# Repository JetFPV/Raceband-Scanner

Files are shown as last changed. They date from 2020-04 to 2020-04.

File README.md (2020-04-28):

# Raceband Scanner

**This device is a  scanner for the RaceBand 5.8G to check available channels for FPV Pilots.  
The result is shown on the device using LEDs and a screen can be added to view the scanning graph or display the video feed from the selected channel. The device can be used on the field using a lipo battery (3 to 6S) or at home with micro usb.**  

<p align="left">
  
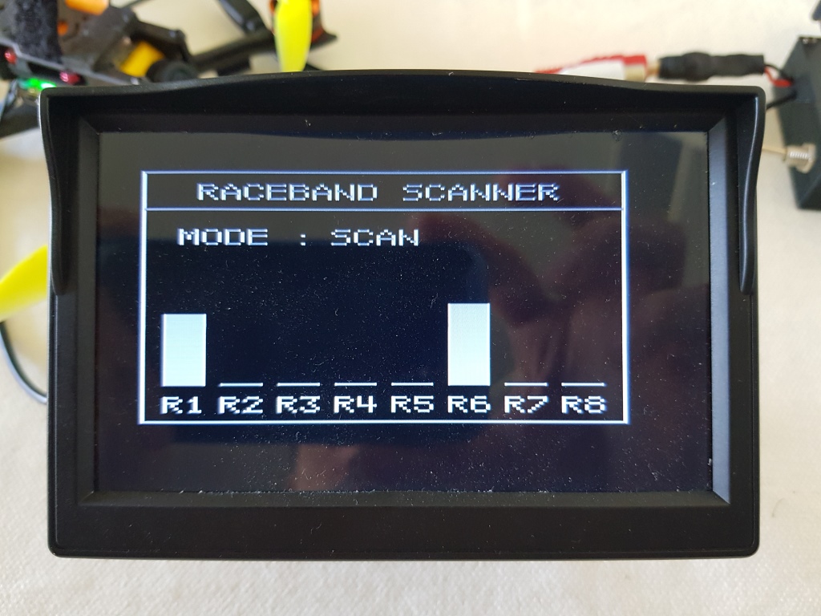
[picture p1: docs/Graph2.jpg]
  
  
</p>

## NEWS FEED
------------------------------------------------
- 2020-04: First version of the project released 
------------------------------------------------

## Contents

<!-- MarkdownTOC depth=0 bracket="round" autolink="true" autoanchor="true" -->

- [Features](#features)
- [Used parts](#used-parts)
- [Wiring](#wiring)
- [3D Case](#3d-case)
- [Arduino Code](#arduino-code)
- [User Guide](#user-guide)
- [Recognition](#recognition)
- [Contributors](#contributors)

<!-- /MarkdownTOC -->

## Features
- Can display video from the drone on the 5,8Ghz Raceband
- Can scan the 8 channels to check if there is a signal and display result on Led and screen if available
- 3 modes included : Manual / Automatic / Scanner    
	=> Manual : Change manually channel from R1 to R8    
	=> Automatic : Switch to channel whith highest signal on   
	=> Scanner : Display available channels on the LEDs and show graph on the screen    
- Power supply by Lipo battery (3 to 6S) or Micro USB Port (for the device only, use external power for the screen in that case)
- Lipo voltage monitoring : Display level of batery when plugging the battery and check if low during usage (turn red + beep)
- Mario Bross sounds ;-)

## Used parts

- 1x PCB Prototype board 50x70mm => https://banggood.app.link/N559qmOQJ5
- 1x RX5808 Module 5.8G Receiver module => https://banggood.app.link/6v3u5r1tJ5
- 1x Passive Buzzer 12mm (Optional) => https://banggood.app.link/EE6gt1oLJ5
- 2x Push Buttons Switch Momentary => https://banggood.app.link/4OSGzJBLJ5 or from kit https://banggood.app.link/t9bOLoGLJ5
- 1x DC-DC Step down converter (set to 9V) => https://banggood.app.link/IfqrpMOLJ5
- 1x 8 LEDS WS2812 5050 RGB => https://banggood.app.link/PKKfUEVLJ5
- 1x Arduino nano V3 : https://banggood.app.link/OwPY6x5LJ5
- 5x Resistors => (2x 220 / 2x 1k / 1x 470)
- 1x XT60 => https://banggood.app.link/CkOhsbz5N5
- 8x M2 Screws 4mm
*** Optional screen but nice to have :) ***
- 1x TFT LCD FPV Mini Monitor Screen Displayer (Optional) => https://banggood.app.link/BduELWmQJ5
- 1x RCA Female => https://banggood.app.link/1RLBWa3KJ5
- 1x DC Male => https://banggood.app.link/rKf3vaM5N5
- 1x 2 positions ON/ON switch : https://banggood.app.link/S85dgTBMJ5

## Wiring

I used the PCB Prototype 50x70 board for wiring.<br>
Use the schematic and pictures bellow to locate the component exactly the same if you intend to use the 3D Printed case, especially XT60, the 2 buttons and the arduino nano

Don't forget to set DC-DC Stepdown cenverter to 9V-10V using a small screwdriver and a multimeter.<br>
I noticed 12V is too much for the arduino (at least for a clone...).

<p align="left">
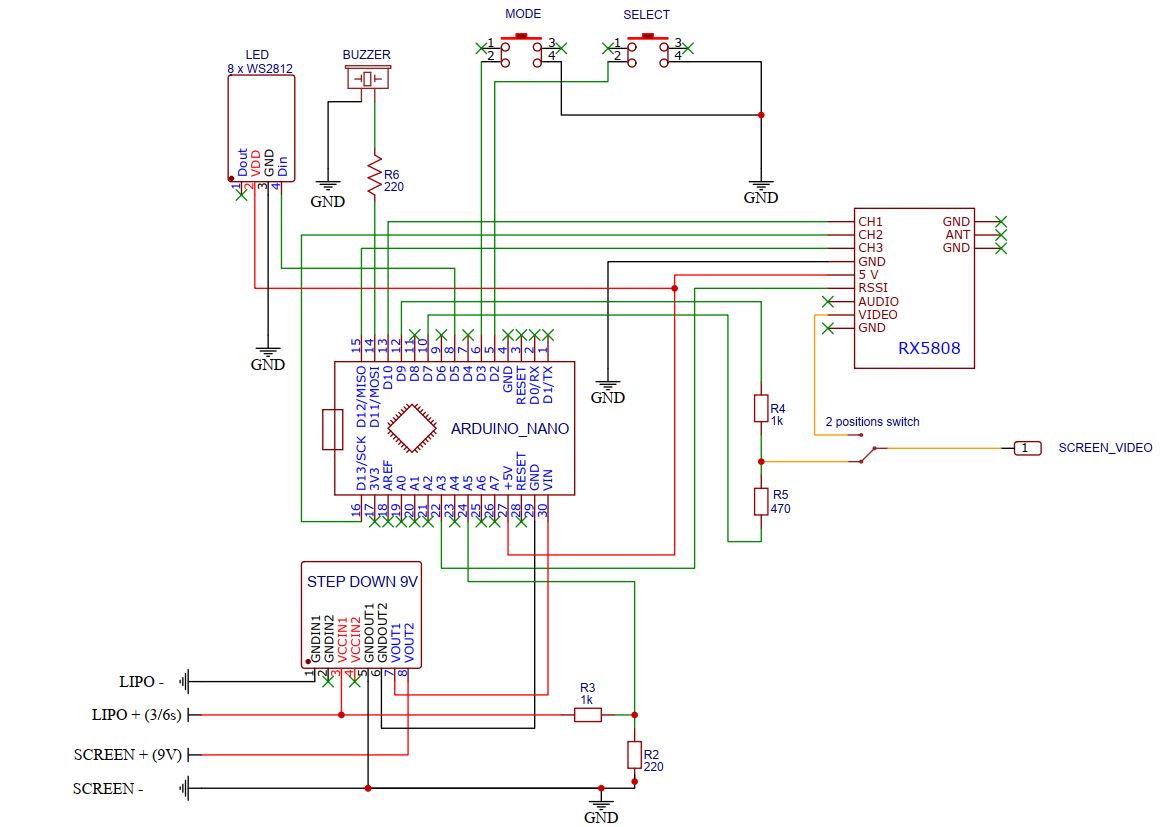
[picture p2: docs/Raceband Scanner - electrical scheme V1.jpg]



</p>

## 3D Printed Case

STL file is available in 3D case folder.   
Print in PLA with 100% infill.   
You will need 8 small M2 screws (3 / 4mm) to assemble PCB into the case and close the lid.    

<p align="left">
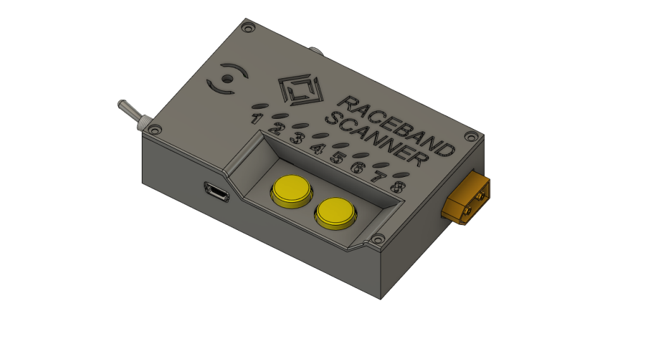
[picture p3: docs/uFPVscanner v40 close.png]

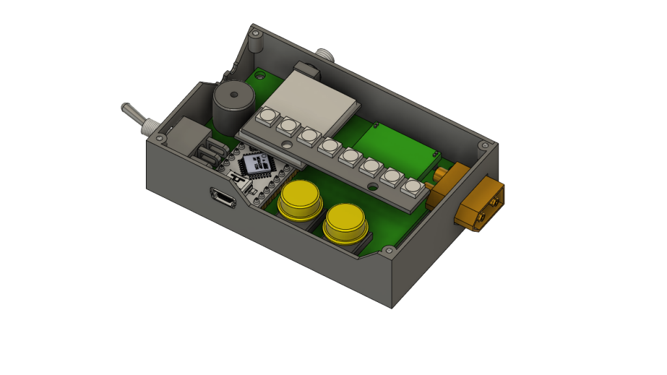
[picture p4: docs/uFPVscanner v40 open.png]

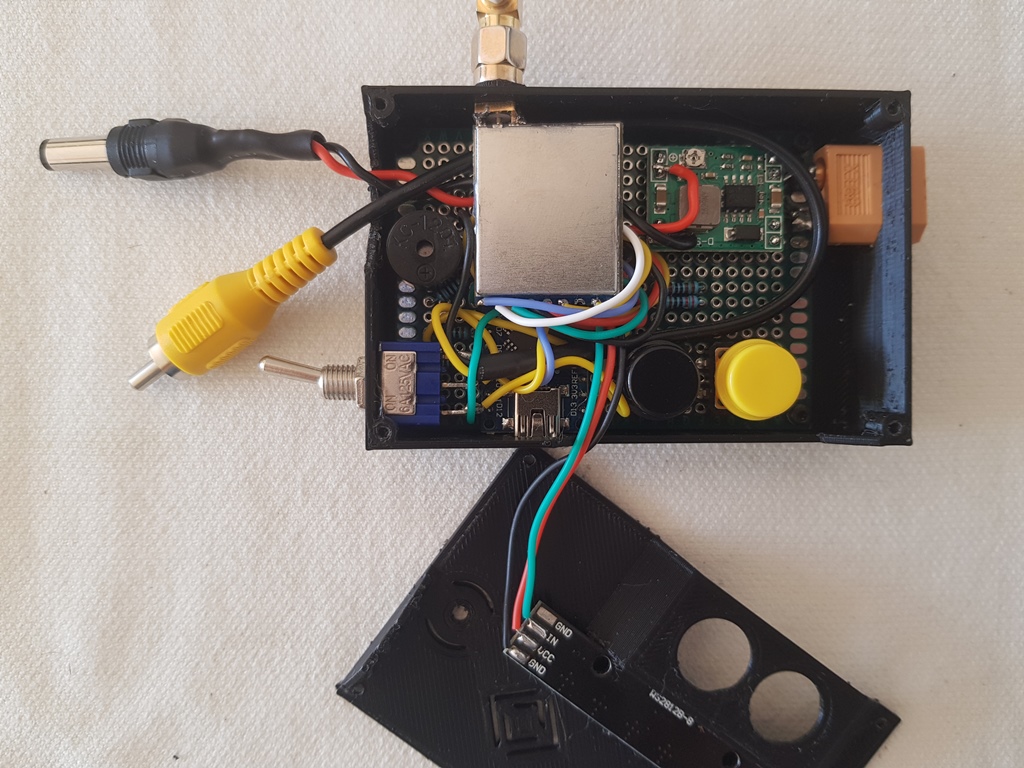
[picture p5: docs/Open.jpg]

</p>

## Arduino Code

Download the project from Arduino folder, open **Raceband_Scanner.ino** file with Arduino IDE (https://www.arduino.cc/en/main/software) and upload to the arduino nano.
In Arduino IDE -> Sketch -> Include Library -> Manage Libraries, search and install for **"FastLED"** and **"TVout"**

Note : FastLED might give you a warning message about version compatibility during upload which is OK.

The code is distrubuted under the MIT license.

## User Guide

When powered with LIPO, first bargraph show LIPO Status :
- 4 to 8 LEDs ON = Green => OK (about >3,8V / Cell)
- 2 to 3 LEDs ON = Orange => Storage (about 3,5 to 3,8V / Cell)
- 1 LED = Red => Low Battery (<3.5V / Cell)

Then Lipo show **Blue** Led showing selected channel.
   
**Buttons :**
- BLACK => Change Mode (Show the mode in **purple** LED)
- YELLOW => Select
    
**MODE button switch between modes :**
- Mode 1 (1 purple led) : Manual change of channel with Select button
- Mode 2 (2 purple leds) : Search for channel with highest signal when pressing select
- Mode 3 (3 purple leds) : Scanner mode, show green for available channels and red for busy channel
 
Raceband Scanner Video (https://youtu.be/IBXWHqRhws8)

## Recognition

- SPI driver based on fs_skyrf_58g-main.c by Simon Chambers
- TVOUT by Myles Metzel

## Contributors

Contributors are very welcome, I'm not either a professional developper nor a professional electronician.<br>
The code and schematic can probably be improved a lot.

For next versions, here is a list of possible improvement in my head :
- Custom PCB
- Use interuptions for better reaction of buttons
- Slide button with 6 poles instead of toggle switch to get input from the video switch and therefore be used as Mode button (Video <=> Scanner)
- Have only one button
- Make it smaller
- Integrate DC screen supply & video directly in the case

Feel free to ask questions, suggest improvements, report your usage results.

=> Happy flying ! <=

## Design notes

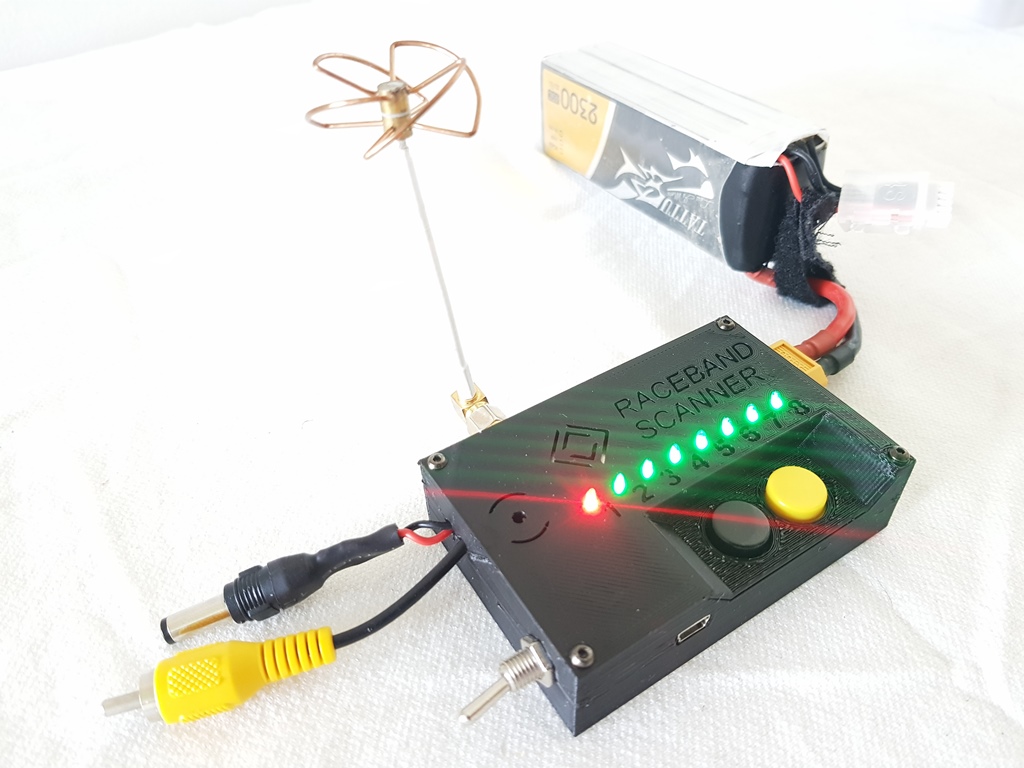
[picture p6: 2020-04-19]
docs/Raceband Scanner 1.jpg

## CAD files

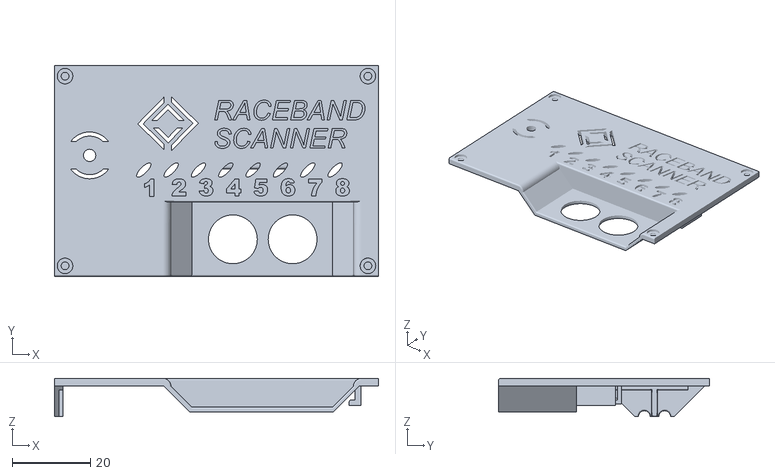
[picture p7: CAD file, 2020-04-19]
3D Case/RACEBAND SCANNER - Upper case V1_4.stl
83.0 x 54.0 x 9.77

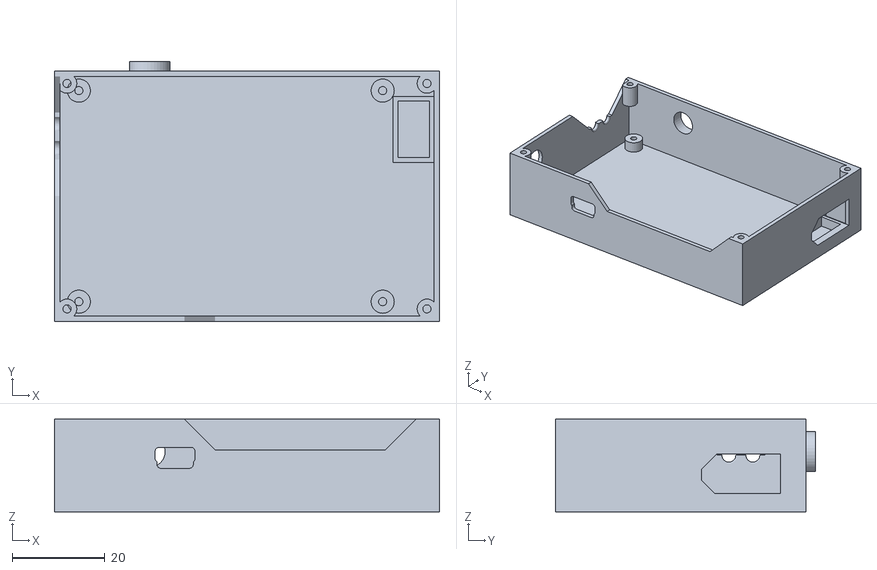
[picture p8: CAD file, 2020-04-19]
3D Case/RACEBAND SCANNER - Lower case V1_4.stl
83.0 x 56.0 x 20.0

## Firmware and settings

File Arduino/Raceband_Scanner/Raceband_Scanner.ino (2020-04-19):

/**
 * DIY RAceband Scanner by Jérémie Tondu (Jet FPV)
 * SPI driver based on fs_skyrf_58g-main.c by Simon Chambers
 * TVOUT by Myles Metzel

The MIT License (MIT)

Copyright (c) 2020 by Jérémie Tondu (Jet FPV)

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
THE SOFTWARE IS PROVIDED "AS IS", WITHOUT WARRANTY OF ANY KIND, EXPRESS OR
IMPLIED, INCLUDING BUT NOT LIMITED TO THE WARRANTIES OF MERCHANTABILITY,
FITNESS FOR A PARTICULAR PURPOSE AND NONINFRINGEMENT. IN NO EVENT SHALL THE
AUTHORS OR COPYRIGHT HOLDERS BE LIABLE FOR ANY CLAIM, DAMAGES OR OTHER
LIABILITY, WHETHER IN AN ACTION OF CONTRACT, TORT OR OTHERWISE, ARISING FROM,
OUT OF OR IN CONNECTION WITH THE SOFTWARE OR THE USE OR OTHER DEALINGS IN THE
SOFTWARE.
*/

// TVout setup
#include <avr/pgmspace.h>
#include <TVout.h>
#include <fontALL.h>

// Configuration of RX5808 VRX
#define RSSI_ADC A3 // RSSI pin on Arduino A3
#define SPI_DATA_PIN 10 // CH1 pin RX5808 => D10
#define SPI_SS_PIN 13 // CH2 pin RX5808 => D13
#define SPI_CLOCK_PIN 12 // CH3 pin RX5808 => D12
#define RSSI_AVERAGE_READS 5 // Number of ADC reads (averaged) per iteration
#define RSSI_THRESHOLD 200
#define MIN_RSSI 135 // Check RSSI when nothing is plugged
#define MAX_RSSI 270 // Check RSSI when drone is plugged next to RX5808
#define MIN_BAR_OFFSET 35
#define MAX_BAR_OFFSET 80

// Configuration of other pins
#define BUZZER_PIN 11 // Buzzer pin is defined by TVout on pin 11
#define BUTTON_M 3 // Button MODE on Pin 2
#define BUTTON_S 2 // Button SELECT on Pin 3

// Lipo monitor Input
#define LIPO_ADC A5 // Lipo voltage divider input on A5
#define LIPO_AVERAGE_READS 5 // Number of ADC reads (averaged) per iteration
#define VOLTAGE_CIRCUIT 5 // Voltage of input circuit for accurate reading of LIPO Voltage
#define LIPO_MIN_V 3.2 // Voltage minimum for each cell of lipo
#define LIPO_MAX_V 4.2 // Voltage maximum for each cell of lipo

// Global variable declaration and initialization
byte channelDetected = 1;
byte channelSelect = 1; // By default channel is 8 (only very first startup)
byte bandSelect = 0; // 0 is Raceband - Change for following : 1 Band A - 2 Band B - 3 Band E - 4 Band F - 5 Band D
uint16_t rssi = 0;
uint16_t rssiMax = 0;
uint16_t rssiScaled;
byte caddxPos = 0;
byte storedChannel;
byte channelTV;
bool lipoLow = false;
bool stateM;
bool stateO;
byte mode = 1; 
bool action = false;
bool out = false;
bool outM = false;
bool outO = false;

// LED Setup
#include "FastLED.h"
#include <avr/pgmspace.h>
#define DATA_PIN 5
#define NUM_LEDS 8
CRGB leds[NUM_LEDS];

// Include internal headers & other librairies
#include "rx5808spi.h"
#include "leds.h"
#include "lipo.h"
#include "pitches.h"
#include <EEPROM.h>

TVout TV;

//------ SETUP PART --------------------------------------------------------------------------------------

void setup() {
       
    // initialisation des pin
    pinMode(SPI_SS_PIN, OUTPUT);
    pinMode(SPI_DATA_PIN, OUTPUT);
    pinMode(SPI_CLOCK_PIN, OUTPUT);
    pinMode(BUTTON_M, INPUT_PULLUP);
    pinMode(BUTTON_S, INPUT_PULLUP);
    
    // LEDS setup
    FastLED.addLeds<NEOPIXEL, DATA_PIN>(leds, NUM_LEDS);
    Clearleds();
    FastLED.show();

    // Display lipo status on LED
    ShowlipoStatus(); 

    // Start on mode 1 (manual)
    mode = 1;
  
    // Channel select on RX5808 based on EEPROM if exist & set in RX5808
    storedChannel = EEPROM.read(0);
    if ( storedChannel <=8 ){
        channelSelect = storedChannel;
    }
    setChannelModule(channelSelect, bandSelect);
    SetLed(channelSelect);

    //Setup display. (PAL/NTSC, resolution width, resolution height)
    TV.begin(PAL,128,96);
    TV.select_font(font4x6);
    TV.clear_screen();
}

//************************************* MAIN PROGRAM **********************************************************

void loop() {
  
//------------------- GET BUTTON STATUS & MODE / ACTION CHANGE ----------------

    stateM = digitalRead(BUTTON_M);
    stateO = digitalRead(BUTTON_S);

    if ((stateM == LOW && stateO == HIGH) || outM == true) {
        delay(50);
        if (mode<3) { mode++;}
          else { mode = 1; }
        SetLedMode(mode);
        delay(800);
        Clearleds();
        if (mode == 1 || mode == 2) 
        {
          setChannelModule(channelSelect, bandSelect);
          SetLed(channelSelect);
        }
        TV.draw_rect(2, 20,123, 70, BLACK, BLACK);
        outO = false;
        outM = false;
        out = false;
        }    
    else if ((stateO == LOW && stateM == HIGH)  || outO == true) {
        delay(50);
        action = true;
        outO = false;
        outM = false;
        out = false;
        }
    else { 
          action = false; 
        }

//-------------------- TV SCREEN INIT -----------------------------------------
  
      // Display border, tiltle, channel and rssi on the screen
      TV.select_font(font6x8);
      TV.print(15, 5,"RACEBAND SCANNER");
      TV.draw_rect(0,0,127,94,WHITE);
      TV.draw_line(0,14,127,14,WHITE);

       channelTV = 48 + channelSelect;
       TV.print(10, 22, "MODE : ");
       TV.draw_rect(90,22,35,8,BLACK, BLACK);
       if (mode == 1) { TV.print(50, 22, "MANUAL"); } 
       if (mode == 2) { TV.print(50, 22, "AUTO"); }
       if (mode == 3) { TV.print(50, 22, "SCAN"); }

       if (mode == 1 || mode == 2)
       {
          rssi = GetRssi();
          TV.print(10, 32, "CHANNEL : R");
          TV.print(78, 32, channelTV);
          rssi = GetRssi();
          TV.print(10, 42, "RSSI : ");
          rssi = constrain(rssi, MIN_RSSI, MAX_RSSI);
          rssiScaled = map(rssi, MIN_RSSI, MAX_RSSI, 0, 100);
          TV.print(50, 42, rssi);// Display raw number 
          //TV.print(105, 42, "%"); // Display RSSI in %
       }
                
 //--------------- MODE 1 = MANUAL CHANGE OF RACEBAND CHANNEL -----------------  
      if (mode == 1)
      {
          if (action == true)
              {
              channelSelect++;
              if (channelSelect == 9) { channelSelect = 1; }
              setChannelModule(channelSelect, bandSelect);
              SetLed(channelSelect);
              TV.tone(NOTE_G4,35);
              delay(35);
              TV.tone(NOTE_G5,35);
              delay(35);
              TV.tone(NOTE_G6,35);
              delay(35);
              TV.noTone(); 
              }      
          }
 //--------------- MODE 2 = AUTOMATIC : AUTO LOCK ON MAX RSSI DETECTED ---------
  
      if (mode == 2 && action == true)
      {
        // Detect Raceband Channel with higher RSSI & Set RX5808 to this channel
        channelDetected = ChannelMaxRssi();
        if ( (channelDetected != channelSelect) && (channelDetected != 0) )
        {
            channelSelect = channelDetected;
            setChannelModule(channelSelect, bandSelect);
            SetLed(channelSelect);
            TV.tone(NOTE_E6,125);
            delay(130);
            TV.tone(NOTE_G6,125);
            delay(130);
            TV.tone(NOTE_E7,125);
            delay(130);
            TV.tone(NOTE_C7,125);
            delay(130);
            TV.tone(NOTE_D7,125);
            delay(130);
            TV.tone(NOTE_G7,125);
            delay(125);
            TV.noTone();
        }
        else {
            setChannelModule(channelSelect, bandSelect);
            SetLed(channelSelect);
        }
      }
 //--------------- MODE 3 = SCANNER MODE -------------------------------------
   
      if (mode == 3)
      {
              TV.draw_rect(2, 30,123, 60, BLACK, BLACK);          
              for (byte i = 1; i < 9; i++) 
                  {
                  channelTV = 48 + i;
                  TV.select_font(font6x8);  
                  TV.print((15*i)-9, 85, "R");
                  TV.print((15*i)-3, 85, channelTV);
                  rssi = RaceBandScan(i);
                  if (rssi < RSSI_THRESHOLD) { 
                        leds[i-1] = CRGB::Green; }
                  else {
                        leds[i-1] = CRGB::Red; }
                  }
              outM = false;
              outO = false;
              out = false;
              FastLED.show();
              do {
               for (byte i = 1; i < 9; i++) 
                {
                    stateM = digitalRead(BUTTON_M);
                    stateO = digitalRead(BUTTON_S);
                    
                    if (stateM == LOW){ 
                      outM = true;}
                      else   {
                      outM = false;}
                    if (stateO == LOW){
                      outO = true;}
                      else   {
                      outO = false;}
                    if (outM == true || outO == true)
                    {
                        out = true;
                    }
                    rssi = RaceBandScan(i);     
                    rssi = constrain(rssi, MIN_RSSI, MAX_RSSI); 
                    rssiScaled = map(rssi, MIN_RSSI, MAX_RSSI, MAX_BAR_OFFSET, MIN_BAR_OFFSET);                  
                    TV.draw_rect((15*i)-9, MIN_BAR_OFFSET, 10, MAX_BAR_OFFSET-MIN_BAR_OFFSET, BLACK, BLACK);
                    TV.draw_rect((15*i)-9, rssiScaled , 10, MAX_BAR_OFFSET-rssiScaled, WHITE, WHITE);                 
                }
              }while (out == false);              
    }      
//-----------LIPO VOLTAGE CHECK & WRITE ON EEPROM  ----------------------------
     
      // Check if LIPO Voltage is low    
      lipoLow = CheckLipoVolt();
      if (lipoLow == true) {
          TV.tone(850, 200);
          delay (600);
          TV.tone(850, 200);
          delay (600);
      };
      EEPROM.write(0, channelSelect);
      TV.delay_frame(10);

}

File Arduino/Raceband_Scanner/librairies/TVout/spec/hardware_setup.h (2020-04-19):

/*
 Copyright (c) 2010 Myles Metzer

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
 THE SOFTWARE IS PROVIDED "AS IS", WITHOUT WARRANTY OF ANY KIND,
 EXPRESS OR IMPLIED, INCLUDING BUT NOT LIMITED TO THE WARRANTIES
 OF MERCHANTABILITY, FITNESS FOR A PARTICULAR PURPOSE AND
 NONINFRINGEMENT. IN NO EVENT SHALL THE AUTHORS OR COPYRIGHT
 HOLDERS BE LIABLE FOR ANY CLAIM, DAMAGES OR OTHER LIABILITY,
 WHETHER IN AN ACTION OF CONTRACT, TORT OR OTHERWISE, ARISING
 FROM, OUT OF OR IN CONNECTION WITH THE SOFTWARE OR THE USE OR
 OTHER DEALINGS IN THE SOFTWARE.
*/

// sound is output on OC2A
// sync output is on OC1A

//ENABLE_FAST_OUTPUT chooses the highest bit of a port over the original output method
//comment out this line to switch back to the original output pins.
#define ENABLE_FAST_OUTPUT

#ifndef HARDWARE_SETUP_H
#define HARDWARE_SETUP_H

// device specific settings.
#if defined(__AVR_ATmega1280__) || defined(__AVR_ATmega1281__) || defined(__AVR_ATmega2560__) || defined(__AVR_ATmega2561__)
#if defined(ENABLE_FAST_OUTPUT)
#define PORT_VID	PORTA
#define	DDR_VID		DDRA
#define VID_PIN		7
#else
//video
#define PORT_VID	PORTB
#define	DDR_VID		DDRB
#define VID_PIN		6
#endif
//sync
#define PORT_SYNC	PORTB
#define DDR_SYNC	DDRB
#define	SYNC_PIN	5
//sound
#define PORT_SND	PORTB
#define DDR_SND		DDRB
#define	SND_PIN		4

#elif defined(__AVR_ATmega644__) || defined(__AVR_ATmega644P__) || defined(__AVR_ATmega1284__) || defined(__AVR_ATmega1284P__)
//video
#if defined(ENABLE_FAST_OUTPUT)
#define PORT_VID	PORTA
#define	DDR_VID		DDRA
#define VID_PIN		7
#else
#define PORT_VID	PORTD
#define	DDR_VID		DDRD
#define VID_PIN		4
#endif
//sync
#define PORT_SYNC	PORTD
#define DDR_SYNC	DDRD
#define SYNC_PIN	5
//sound
#define PORT_SND	PORTD
#define DDR_SND		DDRD
#define	SND_PIN		7

#elif defined(__AVR_ATmega8__) || defined(__AVR_ATmega88__) || defined(__AVR_ATmega168P__) || defined(__AVR_ATmega168__) || defined(__AVR_ATmega328P__) || defined(__AVR_ATmega328__)
//video
#if defined(ENABLE_FAST_OUTPUT)
#define PORT_VID	PORTD
#define	DDR_VID		DDRD
#define	VID_PIN		7
#else
#define PORT_VID	PORTB
#define	DDR_VID		DDRB
#define	VID_PIN		0
#endif
//sync
#define PORT_SYNC	PORTB
#define DDR_SYNC	DDRB
#define SYNC_PIN	1
//sound
#define PORT_SND	PORTB
#define DDR_SND		DDRB
#define	SND_PIN		3 // Try 5 for D13 ? Originally 3
//#define PORT_SND	PORTD
//#define DDR_SND		DDRD
//#define	SND_PIN		3

#elif defined (__AVR_AT90USB1286__)
//video
#define PORT_VID	PORTF
#define	DDR_VID		DDRF
#define	VID_PIN		7
//sync
#define PORT_SYNC	PORTB
#define DDR_SYNC	DDRB
#define SYNC_PIN	5
//sound
#define PORT_SND	PORTB
#define DDR_SND		DDRB
#define	SND_PIN		4
#endif

//automatic BST/BLD/ANDI macro definition
#if VID_PIN == 0
#define BLD_HWS		"bld	r16,0\n\t"
#define BST_HWS		"bst	r16,0\n\t"
#define ANDI_HWS	"andi	r16,0xFE\n"
#elif VID_PIN == 1
#define BLD_HWS		"bld	r16,1\n\t"
#define BST_HWS		"bst	r16,1\n\t"
#define ANDI_HWS	"andi	r16,0xFD\n"
#elif VID_PIN == 2
#define BLD_HWS		"bld	r16,2\n\t"
#define BST_HWS		"bst	r16,2\n\t"
#define ANDI_HWS	"andi	r16,0xFB\n"
#elif VID_PIN == 3
#define BLD_HWS		"bld	r16,3\n\t"
#define BST_HWS		"bst	r16,3\n\t"
#define ANDI_HWS	"andi	r16,0xF7\n"
#elif VID_PIN == 4
#define BLD_HWS		"bld	r16,4\n\t"
#define BST_HWS		"bst	r16,4\n\t"
#define ANDI_HWS	"andi	r16,0xEF\n"
#elif VID_PIN == 5
#define BLD_HWS		"bld	r16,5\n\t"
#define BST_HWS		"bst	r16,5\n\t"
#define ANDI_HWS	"andi	r16,0xDF\n"
#elif VID_PIN == 6
#define BLD_HWS		"bld	r16,6\n\t"
#define BST_HWS		"bst	r16,6\n\t"
#define ANDI_HWS	"andi	r16,0xBF\n"
#elif VID_PIN == 7
#define BLD_HWS		"bld	r16,7\n\t"
#define BST_HWS		"bst	r16,7\n\t"
#define ANDI_HWS	"andi	r16,0x7F\n"
#endif
#endif

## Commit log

2020-04-19 Arduino code added
2020-04-19 3D Case added
    [RACEBAND SCANNER - Lower case V1_4.stl, RACEBAND SCANNER - Upper case V1_4.stl]
